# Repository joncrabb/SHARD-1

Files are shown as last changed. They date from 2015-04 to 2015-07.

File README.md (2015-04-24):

# SHARD-1
Code for the Surrey High Altitude Radiation Detector (SHARD-1)

Code written for 2 Arduino Nano controllers. 

To be used as payload with the Surrey EARS (Electronics and Amateur Radio Society) High Altitude Balloon Project

Go here to the EARS repositoryy containing PCB designs and code for the OBC: https://github.com/SurreyEARS/EARS-HAB

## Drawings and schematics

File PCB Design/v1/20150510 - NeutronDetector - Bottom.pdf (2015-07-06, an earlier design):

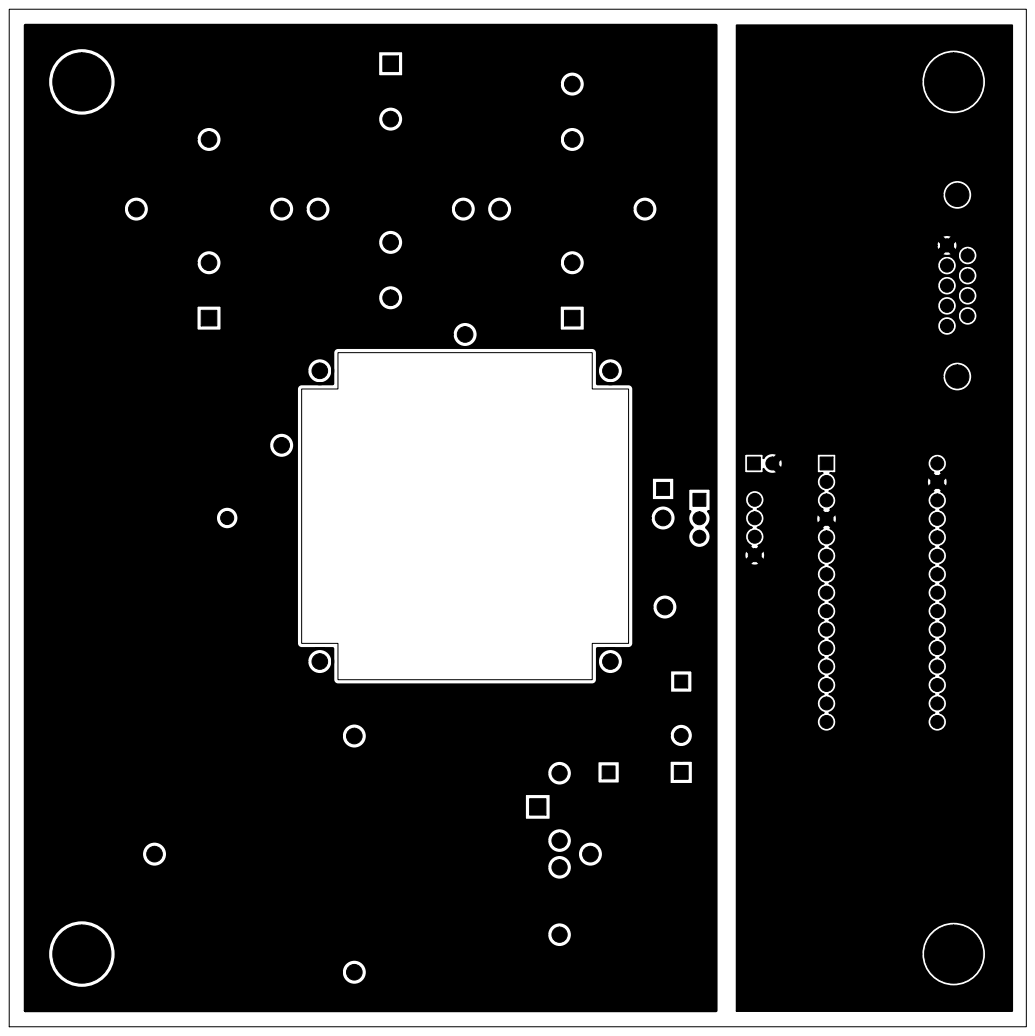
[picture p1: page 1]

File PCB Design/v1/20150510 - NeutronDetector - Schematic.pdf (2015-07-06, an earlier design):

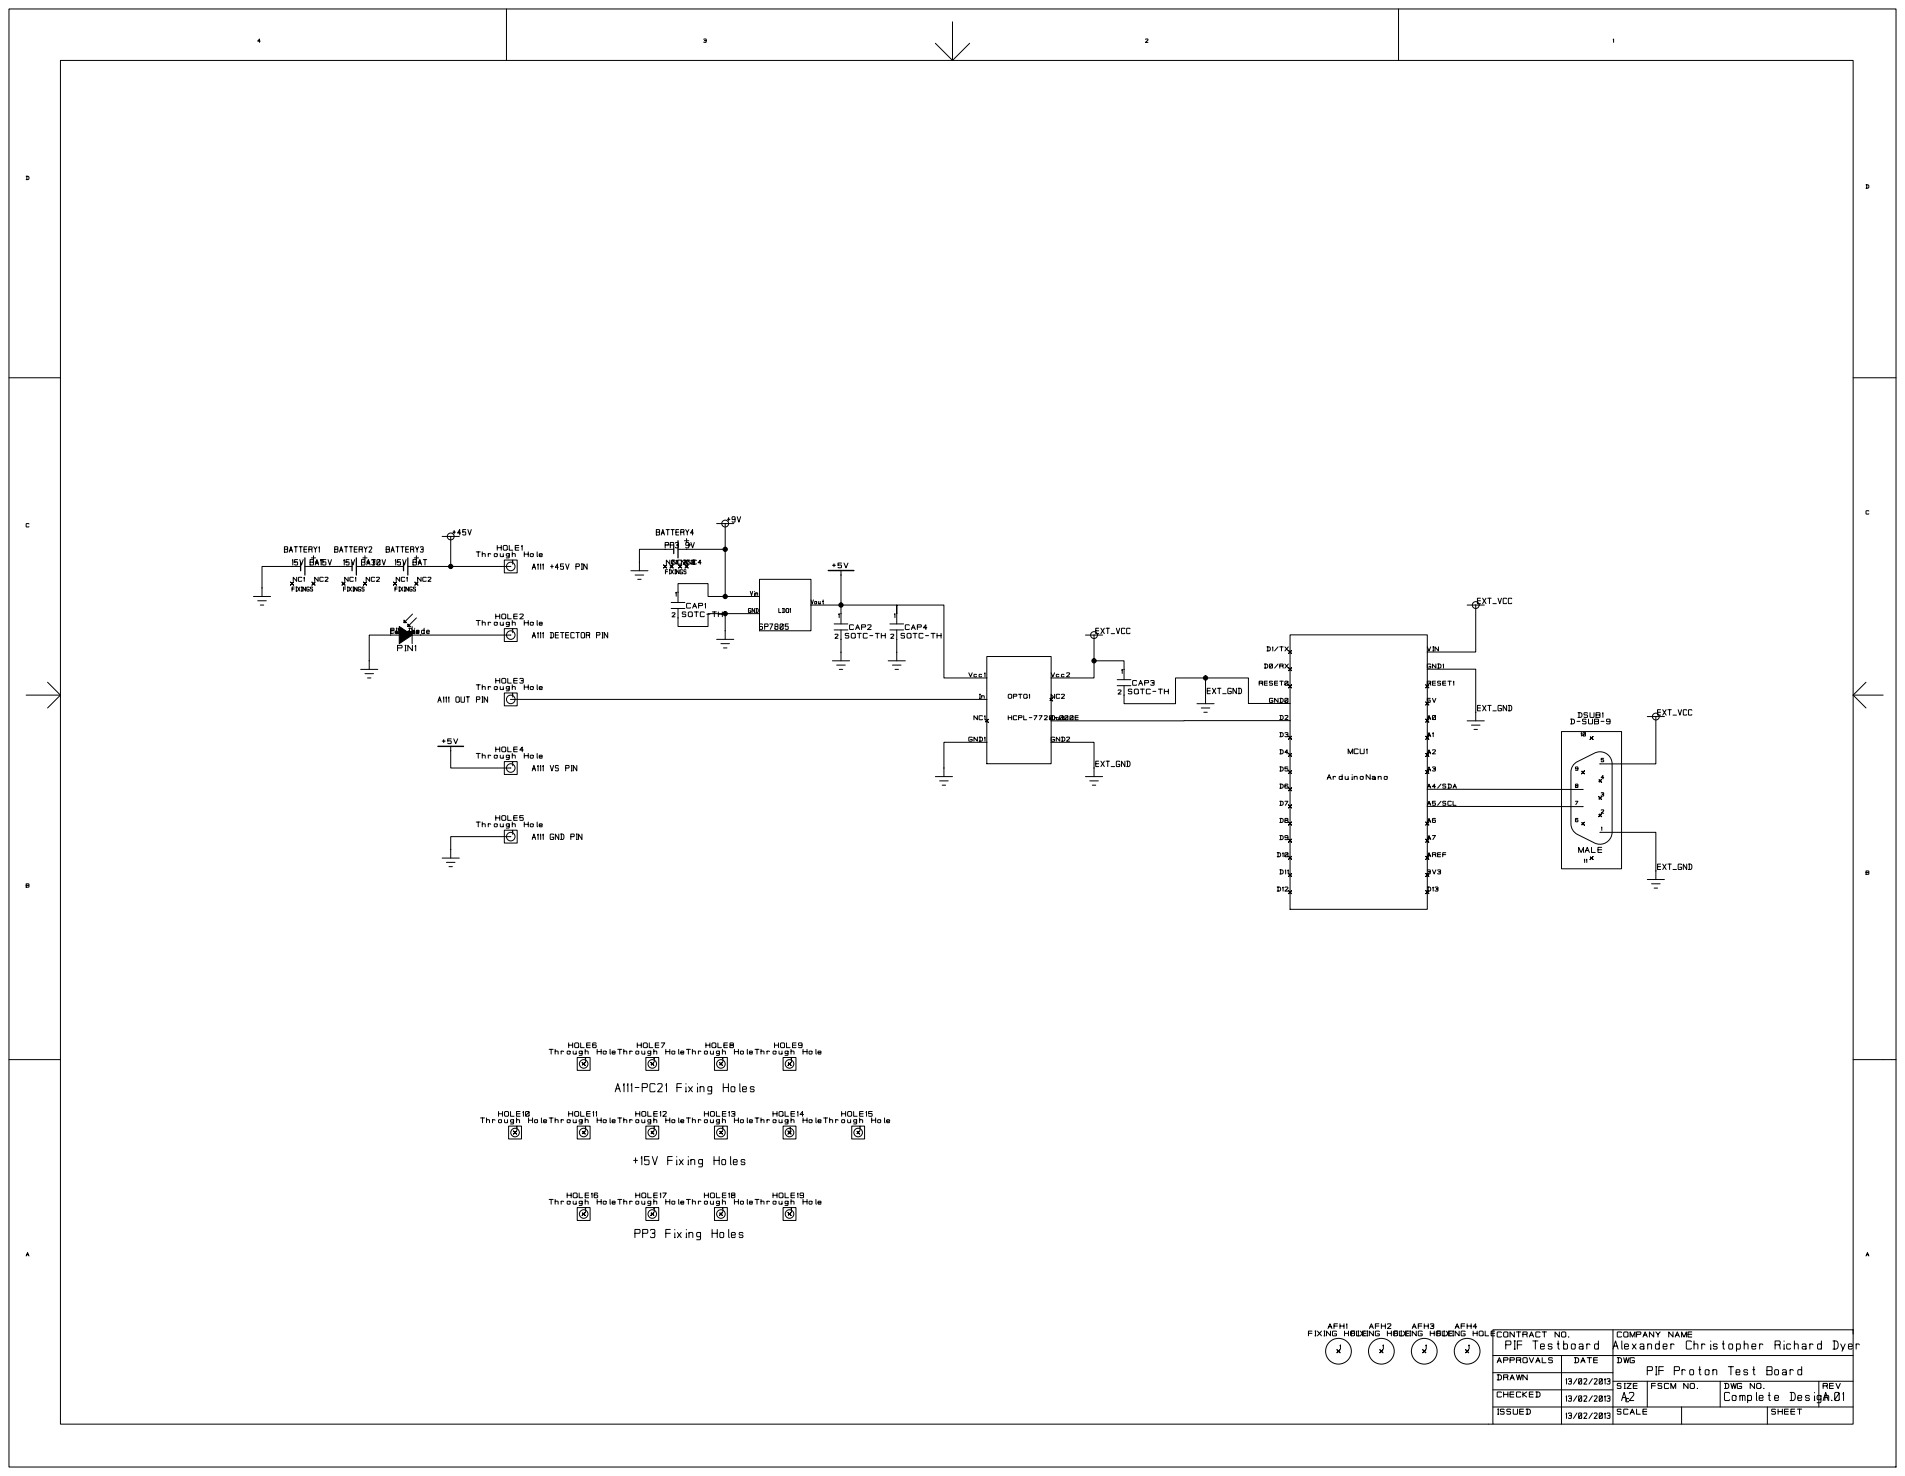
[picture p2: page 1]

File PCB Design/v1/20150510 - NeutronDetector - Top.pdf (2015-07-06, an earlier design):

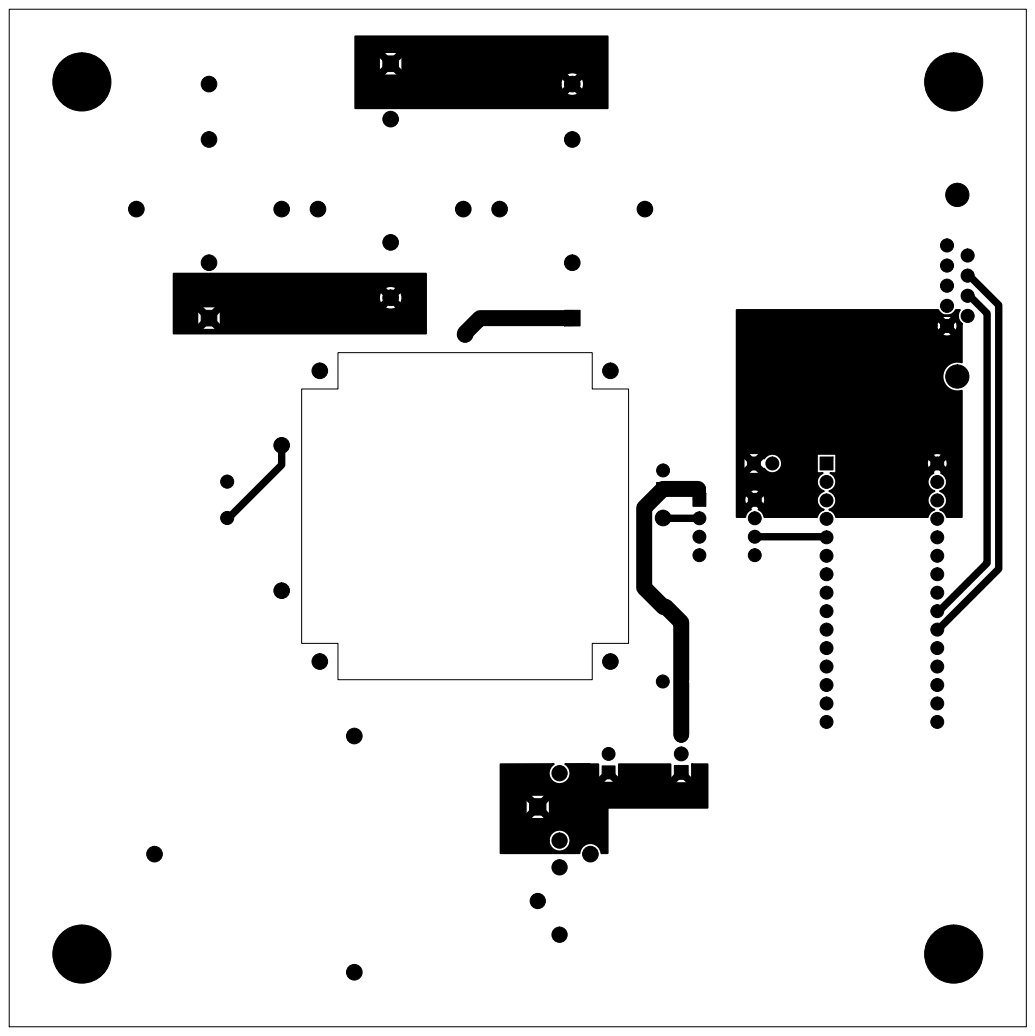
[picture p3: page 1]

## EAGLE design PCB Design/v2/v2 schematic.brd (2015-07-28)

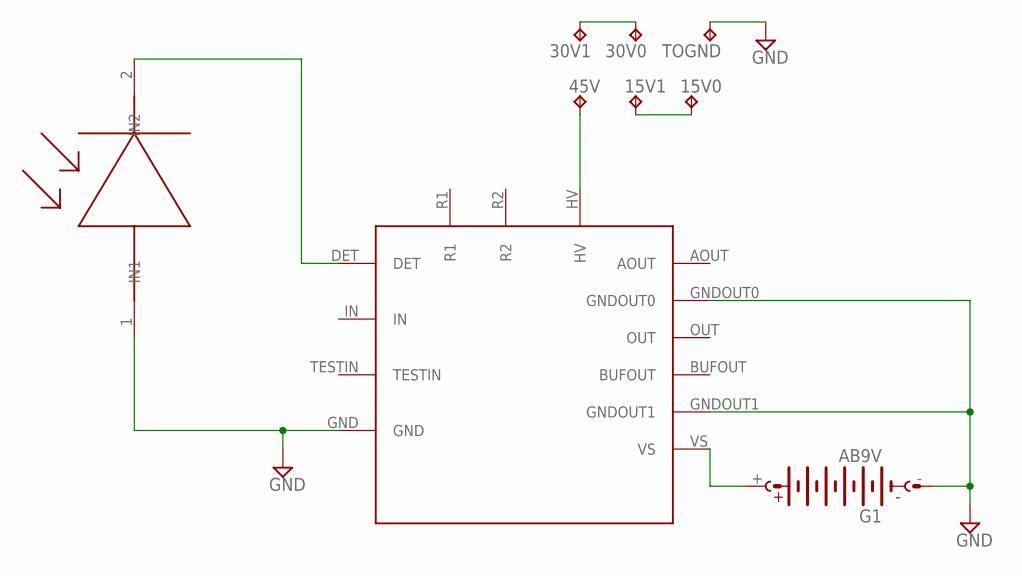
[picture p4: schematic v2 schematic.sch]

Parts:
15V0, 15V1, 30V0, 30V1, 45V: TP-063
G1: AB9V
PC21: A111
PINDIODE: S3590-08
TOGND: TP-063

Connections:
GND: G1.-, PC21.GND, PC21.GNDOUT0, PC21.GNDOUT1, PINDIODE.1 (IN1), TOGND.1
unnamed: 45V.1, PC21.HV
unnamed: 30V0.1, 30V1.1
unnamed: 15V0.1, 15V1.1
unnamed: G1.+, PC21.VS
unnamed: PC21.DET, PINDIODE.2 (IN2)

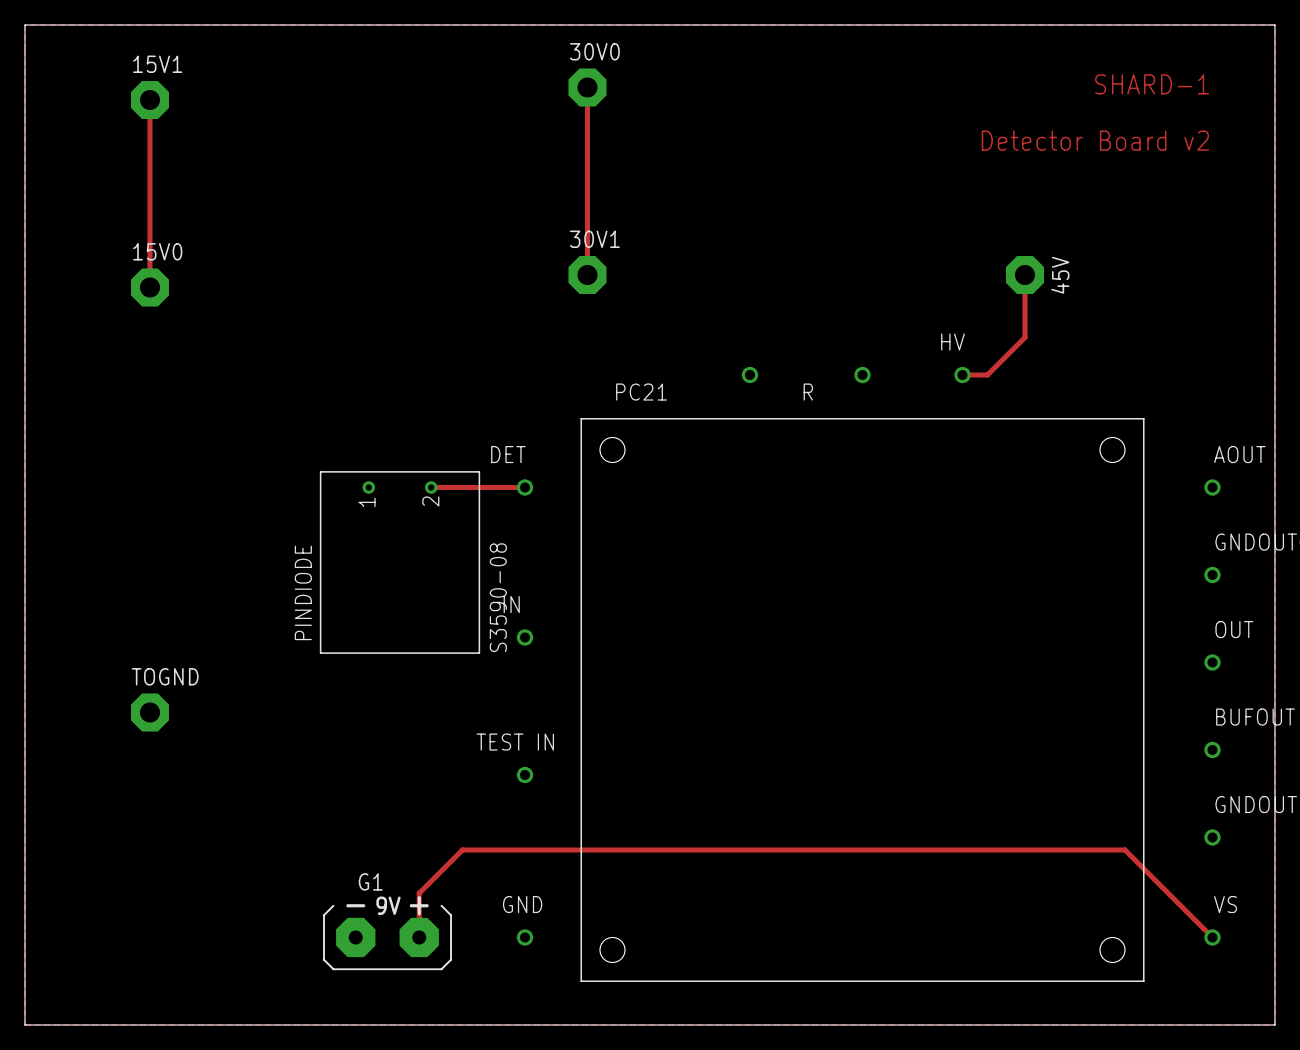
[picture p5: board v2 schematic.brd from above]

Board: 2 copper layers, 100.0 x 80.0 mm, 9 parts (0 on the bottom side), 6 nets.

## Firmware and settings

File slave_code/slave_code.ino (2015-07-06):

///////////////////////////////////
/*This is the code needed for the SHARD-1 payload computer

Version: 1.1
Created by: Jonathan Crabb
Email: jc00300@surrey.ac.uk

Version log
v1.0: First version that worked completely

v1.1: Added the variable 'dataout' which is updated every 30 seconds to 
send over I2C to ensure it keeps to a time resolution of 30s. Also added some debugging code.

v1.2: It now disables the interrupts when reading the I2C is being used. This is so that the data can be taken off the device.
However, this now adds some unwanted deadtime in the detector which could be a problem at high count rates.
*/


/////////////////////////////////
//I2C start
#include <Wire.h>

const byte SlaveDeviceId = 1;
byte LastMasterCommand = 0;

int led = 13; //Used for debugging
int dataout;
///////////////////////////////

///////////////////////////////
//Interrupt start
volatile unsigned int count = 0;
///////////////////////////////

void setup() {
  attachInterrupt(0, countpulses, RISING); // interrupt 0 = pin 2      
  Serial.begin(9600);
  Wire.begin(SlaveDeviceId); //Start I2C Bus as a Slave (Device Number 1)
  Wire.onReceive(receiveCommand); // register event
  Wire.onRequest(slavesRespond);  // register callback event
  Serial.println ("Reset");
}

void loop() {
  //Serial.println(count); //Code for testing the counting
  delay(10000); //30 Second delay
  dataout = count + dataout; //Variable to send over I2C is updated every 30 seconds
  count = 0;
}

void countpulses() {  
  count++;
  //Used for debugging
  //Makes the 'L' LED flash when the ISR is serviced.
  digitalWrite(led,HIGH);
  delay(100);
  digitalWrite(led,LOW);
}

void receiveCommand(int howMany){
  detachInterrupt(0);
  LastMasterCommand = Wire.read(); // 1 byte (maximum 256 commands)
  attachInterrupt(0, countpulses, RISING); // interrupt 0 = pin 2      
}

void slavesRespond(){
  detachInterrupt(0);
  int returnValue = 0;
 
  switch(LastMasterCommand){
    case 0:   // No new command was received
      Wire.write("NA");
    break;
    
    case 1: //send counts
      returnValue = dataout;
  }
 
  uint8_t buffer[2];              // split integer return value into two bytes buffer
  buffer[0] = returnValue >> 8;
  buffer[1] = returnValue & 0xff;
  Wire.write(buffer, 2);          // return slave's response to last command
  LastMasterCommand = 0;          // null last Master's command and wait for next
  dataout = 0;
  attachInterrupt(0, countpulses, RISING); // interrupt 0 = pin 2      

}

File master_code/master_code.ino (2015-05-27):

 
#include <Wire.h>
unsigned long time;
double Time;
void setup()
{
  Wire.begin();        // join i2c bus (address optional for master)
  Serial.begin(9600);  // start serial for output
  Serial.println("Reset");
}
 
void loop()
{
  int x = GetCount(1); // 1 - slave's address
  time = millis();
  Time = time/1000.0;
  Serial.print("Time:");
  Serial.print(Time);
  Serial.print(" ");
  Serial.print("Count Value:");
  Serial.println(x);
  
  delay (1000);
}
 
int GetCount(byte SlaveDeviceId){
 
  // SEND COMMAND 
  Wire.beginTransmission(SlaveDeviceId);
  Wire.write(1); // Transfer command ("1") to get coun value;
  delay(10);
 
  // GET RESPONSE
  int receivedValue;
  int available = Wire.requestFrom(SlaveDeviceId, (byte)2);
  if(available == 2)
  {
    receivedValue = Wire.read() << 8 | Wire.read(); // combine two bytes into integer
  }
  else
  {
    Serial.print("ERROR: Unexpected number of bytes received (Payload): ");
    Serial.println(available);
  }
  Wire.endTransmission();
  
  return receivedValue;
} 

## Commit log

2015-05-07 Slave code now works completely.
    Tested with Arduino Nano to read out the count through the serial port.
2015-05-07 Slave code now works, tested with an Arduino Nano.
2015-05-13 i2c now works fine.
2015-05-27 Updated slave code: v1.2: It now disables the interrupts when reading the I2C is being used. This is so that the data can be taken off the device. However, this now adds some unwanted deadtime in the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
    Updated Master code so it reads every second (for testing)
    [master_code.ino, slave_code.ino]
2015-07-06 Updated Repository with PCB designs of the first version.
    Added slave code that flew on the EARS balloon.
2015-07-06 Added v2 design (unfinished)
    [v2 schematic.brd, v2 schematic.sch]
2015-07-10 Added SHARD-1 Library
    Finalised v2 board for manufacturing.
    [v2 schematic.brd, v2 schematic.sch]
2015-07-10 Updated pin connections for A111 Chip part
2015-07-19 Updated PCB design so diode is now reversed bias (correct)
    [v2 schematic.brd, v2 schematic.sch]
2015-07-28 Updated design so the batteries now fit.
    Also discovered a problem with the battery clips having two holes!
    Fixed design for it now (have to drill holes separately)
    [v2 schematic.brd]
2015-07-28 Final v2 design
    [v2 schematic.brd]
